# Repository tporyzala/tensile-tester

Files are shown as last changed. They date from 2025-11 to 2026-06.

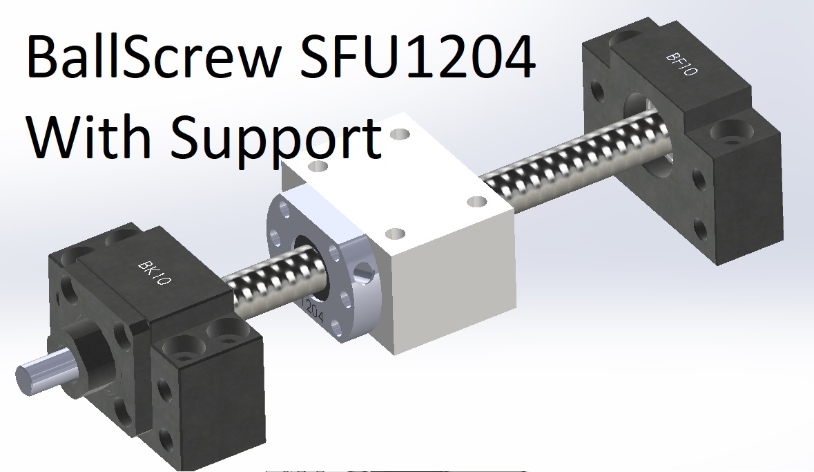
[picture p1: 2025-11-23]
cad/SFU/Sfu1204.jpg

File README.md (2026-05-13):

# Tensile tester repository

This repository contains mechanical, documentation, and experimental assets alongside the software stack.

The software and firmware implementation live under:

```text
src/
```

The source tree currently includes:

- Raspberry Pi FastAPI application
- SQLite persistence layer
- WebSocket/Plotly live telemetry UI
- Arduino Uno firmware for control, safety, telemetry, and button handling
- setup and protocol documentation

See [`src/README.md`](src/README.md) for software architecture, setup, transport selection, serial protocol, and firmware notes.

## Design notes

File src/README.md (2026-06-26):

# Tensile tester ground-zero stack

This `src/` workspace is intentionally small. The current behavior is:

- Arduino Uno reads the HX711 load cell, two jog buttons, and one stop button.
- In setup mode, Button 1 on D2 jogs the load head up while held and Button 2 on D3 jogs it down while held.
- Releasing both jog buttons stops setup jog step pulses. Button 3 on D4 is reported as the stop button.
- During an automated test, Button 1 pauses/resumes and Button 2 or Button 3 stops the run.
- Raspberry Pi serves one automated-test page where the operator defines any number of force or displacement steps.
- The automated-test page keeps an in-memory sample set: one specimen at a time, editable step methods, setup motion sliders, automatic sample numbers, notes, include/exclude controls, force-displacement overlays, setup tare/displacement zeroing, live charts, a raw serial log, and one XLSX workbook export.
- Plots keep accumulating data until the operator clicks the plot Clear button.

There is no database, persistent run storage across app restarts, limit switch handling, overload shutoff, audit trail, ASTM report generation, barcode workflow, or emergency-stop chain in this version.

## Layout

```text
src/
|-- app/
|   |-- __init__.py
|   |-- main.py              FastAPI web API and serial bridge
|   `-- static/
|       |-- test.html        Automated-test page
|       |-- styles.css       Shared page appearance
|       |-- live-charts.js   Plotly chart adapter and navigation
|       |-- vendor/          Vendored browser libraries
|       `-- test.js          Automated-test page behavior
|-- firmware/
|   `-- arduino_uno/
|       |-- include/
|       |   `-- HardwareConfig.h
|       |-- src/
|       |   `-- main.cpp
|       `-- platformio.ini
|-- requirements.txt
|-- tests/
|   `-- test_multisample.py
`-- README.md
```

## How It Works

```text
Arduino:
  HX711 + buttons -> motion/test state machine -> serial telemetry

Python app:
  serial telemetry -> MachineSnapshot/TestRunState -> web API
  web commands -> ACK-confirmed Arduino serial commands
  finalized specimen telemetry -> in-memory sample set

Browser:
  automated page polls /api/test/state
  sends setup motion, test, stop, sample-set, and return-to-zero commands
```

The Arduino owns the hardware loop. It reads the HX711, debounces the buttons, updates the stepper, runs the automated-test state machine, and emits `TEL` telemetry every 100 ms.

The Python app owns serial communication, command acknowledgement, API state, sample-set memory, and XLSX workbook generation. Motion, tare, displacement-zero, and test commands are not treated as successful until the expected Arduino `ACK,...` is consumed.

The browser owns only the operator interface. It does not persist test records. Sample sets live in the Python process and disappear when the app restarts or when the operator clicks Clear Set.

## Current Pinout

The firmware uses `INPUT_PULLUP` for the physical buttons, so each button should connect its Arduino pin to ground when pressed.

```text
Stepper PUL-       D12
Stepper DIR-       D11
Stepper ENA-       D10
HX711 data         D5
HX711 clock        D6
Button 1, up       D2
Button 2, down     D3
Button 3, stop     D4
E-stop             unused in this build
```

The current driver assumption is common-positive signal wiring:

```text
PUL+ -> +5V
DIR+ -> +5V
ENA+ -> +5V
D12  -> PUL-
D11  -> DIR-
D10  -> ENA-
```

The firmware always controls ENA on D10. If your driver enables at the wrong logic level, flip `InvertEnable` in `firmware/arduino_uno/include/HardwareConfig.h`.

## Firmware

Stepper pulses and direction are handled by AccelStepper in `DRIVER` mode. Setup jog uses `setSpeed(...)` plus `runSpeed()` with a small firmware-side speed ramp so acceleration changes take effect while keeping the known-good pulse path.

Important motion, test, load-cell, and timing settings live in:

```text
firmware/arduino_uno/include/HardwareConfig.h
```

Current key values:

```cpp
constexpr uint8_t StepPulse = 12;
constexpr uint8_t StepDirection = 11;
constexpr uint8_t StepEnable = 10;
constexpr uint8_t Hx711Data = 5;
constexpr uint8_t Hx711Clock = 6;
constexpr uint8_t ButtonUp = 2;
constexpr uint8_t ButtonDown = 3;
constexpr uint8_t ButtonStop = 4;

constexpr float MotorStepsPerRev = 200.0f;
constexpr float GearboxRatio = 19.203f;
constexpr float ScrewPitchMmPerRev = 4.0f;
constexpr uint16_t Microstepping = 8;

constexpr float MinJogStepRateStepsS = 50.0f;
constexpr float MaxJogStepRateStepsS = 4000.0f;
constexpr float DefaultJogStepRateStepsS = 4000.0f;
constexpr float MinAccelerationStepsS2 = 100.0f;
constexpr float MaxAccelerationStepsS2 = 10000.0f;
constexpr float DefaultAccelerationStepsS2 = 10000.0f;
constexpr uint32_t StepPulseHighMicros = 20;
constexpr bool InvertDirection = false;
constexpr bool InvertStepPulse = true;
constexpr bool InvertEnable = false;
constexpr bool DisableMotorWhenIdle = false;

constexpr int8_t IncreaseLoadDirection = 1;
constexpr float MinStepRateStepsS = 50.0f;
constexpr float MaxStepRateStepsS = 4000.0f;
constexpr float DefaultMaxStepRateStepsS = 2000.0f;
constexpr float ForceKpStepsPerSecondPerNewton = 12.0f;
constexpr float ForceKiStepsPerSecondPerNewtonSecond = 1.0f;
constexpr float ForceKdStepsPerSecondPerNewtonPerSecond = 0.0f;
constexpr float ForceDeadbandN = 0.20f;
constexpr float ForceIntegralLimitNSeconds = 300.0f;
constexpr uint16_t HeartbeatTimeoutMs = 2000;

constexpr uint8_t Hx711Gain = 128;
constexpr float CalibrationSlopeNPerCount = 0.002283289f;
constexpr float CalibrationInterceptN = 0.0f;
constexpr bool InvertSign = false;
constexpr uint32_t TareDurationMs = 5000;

constexpr uint16_t TelemetryPeriodMs = 100;
constexpr uint16_t ButtonDebounceMs = 25;
```

Setup jog and automated tests intentionally have different speed ceilings:

- Setup jog slider: `50` to `4000 steps/s`, default `4000 steps/s`.
- Automated test max-speed slider: `50` to `4000 steps/s`, default `2000 steps/s`.
- Shared acceleration slider: `100` to `10000 steps/s^2`, default `10000 steps/s^2`.
- With the current mechanics, `2000 steps/s` is about `0.2604 mm/s`, and `10000 steps/s^2` is about `1.3019 mm/s^2`, because the conversion is `200 * 19.203 * 8 / 4 = 7681.2 steps/mm`.

PlatformIO dependencies:

```text
bogde/HX711
waspinator/AccelStepper
```

PlatformIO is the firmware build/upload tool. On a clean Raspberry Pi, install it into the repo virtual environment:

```bash
cd ~/tensile-tester/src
python3 -m venv .venv
source .venv/bin/activate
python -m pip install --upgrade pip
python -m pip install -r requirements.txt
python -m pip install platformio
```

Build firmware on the Pi:

```bash
cd ~/tensile-tester/src/firmware/arduino_uno
platformio run
```

Upload firmware:

```bash
platformio run --target upload --upload-port /dev/ttyACM0
```

If `platformio` is not found, activate the repo virtual environment first:

```bash
cd ~/tensile-tester/src
source .venv/bin/activate
```

If PlatformIO reports a broken JSON file under `.pio/libdeps`, clear the generated local PlatformIO cache and rebuild:

```bash
cd ~/tensile-tester/src/firmware/arduino_uno
rm -rf .pio
platformio run
```

On this Windows checkout, the verified local build command is:

```powershell
cd C:\Users\tomek\Desktop\tensile-tester\src
.\.venv\Scripts\platformio.exe run -d firmware\arduino_uno
```

## Web App

Python dependencies are listed in `requirements.txt`:

```text
fastapi
uvicorn[standard]
pyserial
XlsxWriter
```

Run on the Raspberry Pi:

```bash
cd ~/tensile-tester/src
python3 -m venv .venv
source .venv/bin/activate
python -m pip install --upgrade pip
python -m pip install -r requirements.txt
export TENSILE_SERIAL_PORT=/dev/ttyACM0
python -m uvicorn app.main:app --host 0.0.0.0 --port 8000
```

Open:

```text
http://<raspberry-pi-ip>:8000/test
```

The root URL `http://<raspberry-pi-ip>:8000/` redirects to `/test`.

Optional environment variables:

```text
TENSILE_SERIAL_PORT=/dev/ttyACM0
TENSILE_SERIAL_BAUDRATE=115200
TENSILE_SERIAL_RECONNECT_S=2.0
TENSILE_SERIAL_LOG_MAX_LINES=500
```

On Windows, the default serial port is `COM3`. On Linux/Raspberry Pi, the default is `/dev/ttyACM0`.

## Automated Test Mode

Automated test mode is served at:

```text
http://<raspberry-pi-ip>:8000/test
```

The root URL redirects to `/test`, so there is no separate manual-mode page. The sidebar remains in place with the automated-test entry so more pages can be added later.

The left sidebar switches between Automated Test, Calibration, and Setup. Automated Test keeps the live plots, compact machine status, test actions, method steps, sample set, and raw serial log. Calibration captures averaged raw ADC points, fits a linear load-cell calibration, and reports firmware-ready slope/intercept constants for `HardwareConfig.h`. Setup contains tester motion sliders for physical button jog speed, automated-test maximum step rate, and shared acceleration. Slider changes post to `/api/motion`; the Python app sends `SET_MOTION_LIMITS`, waits for `ACK,SET_MOTION_LIMITS`, and only then reports the applied settings.

An automated test has any number of steps. Each step contains:

- target type and value: force in newtons, or crosshead displacement in millimeters
- rate type and value: force in newtons per second, or crosshead displacement in millimeters per second
- hold duration in seconds; zero means ramp-only

Target and rate types are independent. For example, a step can move at `0.02 mm/s` until it reaches `100 N`, or increase the commanded force at `10 N/s` until it reaches `2.0 mm` displacement. Signed target values allow tension/compression or either crosshead direction; rate values are entered as positive magnitudes.

The step table and motion settings can be saved as named test methods. The save icon opens a name prompt; saving with the same sanitized name overwrites that method, while saving with a new name creates a new method. The load icon opens a scrollable method picker. Loaded methods remain editable before running, and can be saved back to the same method or saved under a new name. Method files are JSON documents stored in `data/test-methods` by default; set `TENSILE_METHOD_DIR` to use another directory.

Methods can optionally run a preload initialization before the specimen sample starts. The preload/unload/zero mode moves at the configured initialization rate until the signed preload force is reached, unloads to the configured unload threshold force (`0 N` by default), holds each point for 1 second, sends `ZERO_DISPLACEMENT`, clears the live plot buffer, then starts the real test steps. Initialization telemetry is a utility run and is not archived as specimen data. The max-travel setting aborts initialization if the preload force is not reached within that displacement window.

Each sample gets an automatic sample number, displayed as `Sample 1`, `Sample 2`, and so on. The notes field is where the operator describes the actual specimen. Notes are limited to 200 characters.

Completed and stopped samples are included by default. Faulted samples are retained in the sample set but excluded from overlays until the operator includes them. The sample table shows index, sample, status, method, point count, peak force, final displacement, include/exclude state, and editable notes. Edited notes are reflected in the XLSX export.

The Tare button posts to `/api/tare`. The Python app sends `ZERO_LOAD`, waits for `ACK,ZERO_LOAD`, then the Arduino treats the average of all fresh load-cell readings collected over 5 seconds as the new zero point. Tare collection is non-blocking, so serial handling, button reads, and stepper updates continue while tare is in progress.

The Zero Displacement button posts to `/api/zero-displacement`. The Python app sends `ZERO_DISPLACEMENT` and waits for `ACK,ZERO_DISPLACEMENT`; the Arduino stores the current step count as the new displayed displacement origin without changing stepper motion tracking.

The automated-test page has fixed `+100`, `+10`, `+1`, `-1`, `-10`, and `-100 mm` relative-move buttons. A button posts its fixed offset to `/api/test/move-relative`; the Python app converts the offset to an absolute displacement target from the latest stationary position and runs one displacement step at the configured automated-test maximum step rate. Relative moves use the same stop and fault handling as Return to Zero and are not archived as specimen samples.

The live charts are rendered with the vendored Plotly basic bundle. The Python app retains every received periodic telemetry point for the live plot buffer until the operator clicks Clear, while the browser incrementally renders only the most recent 5,000 live points. The force-time chart can show or hide the commanded-force trace. The force-displacement chart can overlay finalized included samples; overlay display traces are uniformly reduced to at most 2,000 points per sample and drawn without markers. Chart rendering pauses while the Automated Test tab or browser tab is hidden. The workbook export keeps full retained specimen telemetry.

The Set XLSX link downloads one workbook from `/api/test/samples/csv`. The route name is historical; the response is an `.xlsx` file named `tensile-sample-set.xlsx`. The workbook opens with a Summary worksheet containing one row per sample, included-sample statistics, and peak-force/final-displacement charts for all recorded samples. A Method worksheet shows the saved or latest known editable method snapshot, and a Plots worksheet includes a sampled force-displacement overlay for every sample with telemetry. Chart source data remains visible by default so Excel renders plot lines without hidden-data chart options. Each sample still gets its own raw telemetry worksheet named from the automatic sample number, with Excel-invalid worksheet characters replaced and duplicate names made unique. Telemetry columns and simple numeric metadata are written as spreadsheet numbers, while sample IDs, notes, statuses, and method metadata remain text. The workbook includes the method ID, method name, method hash, and full method snapshot used when that sample started.

The Save Set and Open Set buttons persist and reload the current Sample Set as JSON. Saved sets include finalized sample records, editable notes, include flags, full retained specimen telemetry, the per-sample method snapshots, and the current editable method snapshot. Opening a set replaces the current in-memory Sample Set, reloads that editable method into the step table so more samples can be appended, and is rejected while a test, return-to-zero move, relative move, or faulted run is active. Set files are stored in `data/test-sets` by default; set `TENSILE_SAMPLE_SET_DIR` to use another directory.

The Clear Set button clears all in-memory sample records, active sample metadata, current test steps, and retained test telemetry. It is rejected while a specimen test, return-to-zero move, relative move, or faulted run is active.

Live plots do not clear automatically when a new sample starts or finishes, except after a successful preload initialization so the real test starts visually from the new displacement zero. Use the Live Plots Clear button to clear the plot buffer and reset the chart view. Clearing the plots does not delete retained specimen samples or XLSX export data.

## Return To Zero

Return to Zero is a utility operation, not a specimen sample. Utility telemetry is not archived into the sample set and is not included in the workbook export.

The automated-test page supports two return modes:

- Load: one force-target step to `0 N` at the selected load rate, followed by a 1 second hold. The default rate is `10 N/s`.
- Displacement: one displacement-target step to `0 mm` at the selected displacement rate. The default rate tracks the automated-test maximum step-rate slider.

Return to Zero uses the same `START_TEST` / `TEST_STEP` machinery as specimen tests, but it is tracked as `RETURN_ZERO` in the Python app instead of `SPECIMEN`.

Return to Zero is enabled only when the run state is setup/idle or complete. It is disabled while a specimen test is starting, running, paused, waiting for a step, faulted, or while tare/displacement-zero commands are in flight.

## Stop Behavior

There is no separate abort concept in the current codebase.

Stop means:

- stop motor motion
- finalize any active specimen sample as `STOPPED`
- include that stopped sample in overlays and statistics by default
- return the controller and web run state to setup/idle
- keep the partial sample in the sample set until Clear Set or app restart

In automated test mode, the web Stop button posts to `/api/test/stop`. During a test, physical Button 2 and Button 3 both perform the same stop action. If a run faults, Stop is the operator path back to setup before taring, zeroing displacement, clearing the sample set, or starting a return-to-zero move.

## Lite Operator Protection Model

The firmware separates machine permission from test progress:

```text
Frame mode = what the machine is allowed to do
Test phase = where the current firmware test program is
Fault reason = why the machine stopped abnormally
```

Frame modes:

```text
SETUP    setup jog, tare, and displacement zeroing are allowed
ARMED    a test run exists and the Arduino is waiting for the Pi
TESTING  the Arduino owns automated motion or pause
FAULT    motion is stopped; STOP_TEST returns to SETUP
```

Firmware test phases:

```text
NONE          no firmware test is active
WAITING_STEP  waiting for the Pi to send the next TEST_STEP
RAMPING       following the selected force or displacement rate toward the endpoint
HOLDING       holding the force or displacement endpoint for the requested duration
PAUSED        test is paused by Button 1 or PAUSE_TEST
FAULTED       run stopped due to a fault
```

Python run statuses:

```text
IDLE          no active run
STARTING      Pi is sending START_TEST / first TEST_STEP
RUNNING       active automated step is ramping or holding
PAUSED        run is paused
WAITING_NEXT  Pi is sending the next TEST_STEP
COMPLETE      completed run result remains visible until another run or Clear Set
FAULT         faulted run must be stopped before setup actions are allowed
```

Specimen sample statuses:

```text
COMPLETE  sample completed and is included by default
STOPPED   operator stopped the run; partial sample is retained and included by default
FAULT     run faulted; partial sample is retained but excluded by default
```

Normal specimen flow:

```text
SETUP / NONE
  -> START_TEST
ARMED / WAITING_STEP
  -> TEST_STEP
TESTING / RAMPING
  -> target reached
TESTING / HOLDING
  -> hold time reached
ARMED / WAITING_STEP
  -> next TEST_STEP when steps remain

Final hold complete
  -> EVT,TEST_COMPLETE
  -> Arduino returns to SETUP / NONE
  -> Python finalizes the sample as COMPLETE

STOP_TEST from any active or faulted test
  -> motion stops
  -> any active specimen sample is finalized as STOPPED
  -> Arduino and Python return to SETUP / NONE
```

For a force-rate ramp, the Arduino moves the commanded force at the requested rate and the PID converts force error to motor step rate. For a displacement-rate ramp, the Arduino commands crosshead speed directly until the endpoint is reached. A force endpoint is then held under PID control; a displacement endpoint is held by keeping the motor enabled at the reached position. `Kd` is currently `0.0` because the HX711 force signal can be noisy; start with `Kp` and `Ki` before adding derivative action.

## Web API

Pages:

```text
GET  /      redirects to /test
GET  /test
```

Setup/support API:

```text
POST /api/motion
POST /api/tare
POST /api/zero-displacement
GET  /health
```

Automated-test API:

```text
GET  /api/test/state
GET  /api/test/sample-sets
GET  /api/test/sample-sets/{sample_set_id}
POST /api/test/sample-sets
POST /api/test/sample-sets/{sample_set_id}/open
POST /api/test/start
POST /api/test/return-zero
POST /api/test/move-relative
POST /api/test/pause
POST /api/test/resume
POST /api/test/stop
POST /api/test/samples/clear
POST /api/test/samples/include
POST /api/test/samples/notes
GET  /api/test/samples/overlay
GET  /api/test/plots
POST /api/test/plots/clear
GET  /api/test/samples/csv
```

`POST /api/test/start` accepts the current backward-compatible shape:

```json
{
  "steps": [
    {
      "target_type": "FORCE",
      "target_value": 100.0,
      "rate_type": "FORCE",
      "rate_value_per_s": 10.0,
      "hold_duration_s": 5.0
    }
  ]
}
```

It also accepts optional sample metadata:

```json
{
  "sample": {
    "notes": "first coupon"
  },
  "steps": [
    {
      "target_type": "DISPLACEMENT",
      "target_value": 2.0,
      "rate_type": "DISPLACEMENT",
      "rate_value_per_s": 0.02,
      "hold_duration_s": 0.0
    }
  ]
}
```

## Serial Protocol

The app sends `GET_STATUS` after connecting so the raw serial panel shows both transmit and receive traffic.

Pi to Arduino:

```text
PING
GET_STATUS
SET_MOTION_LIMITS,<jog_speed_steps_s>,<test_max_step_rate_steps_s>,<acceleration_steps_s2>
ZERO_LOAD
ZERO_DISPLACEMENT
START_TEST,<run_id>,<step_count>
TEST_STEP,<run_id>,<step_index>,<target_type>,<target_value>,<rate_type>,<rate_value_per_s>,<hold_duration_ms>
TEST_HB,<run_id>
PAUSE_TEST,<run_id>
RESUME_TEST,<run_id>
STOP_TEST,<run_id>
```

For `TEST_STEP`, both `<target_type>` and `<rate_type>` are `FORCE` or `DISPLACEMENT`. Force PID output and displacement-rate commands are limited by the automated-test maximum step-rate setting before they are applied to the motor.

Acknowledgements:

```text
ACK,PING
ACK,SET_MOTION_LIMITS,<applied_jog_speed_steps_s>,<applied_test_max_step_rate_steps_s>,<applied_acceleration_steps_s2>
ACK,ZERO_LOAD
ACK,ZERO_DISPLACEMENT
ACK,START_TEST,<run_id>
ACK,TEST_STEP,<run_id>,<step_index>
ACK,PAUSE_TEST,<run_id>
ACK,RESUME_TEST,<run_id>
ACK,STOP_TEST,<run_id>
```

Test events:

```text
EVT,STEP_COMPLETE,<run_id>,<step_index>
EVT,TEST_COMPLETE,<run_id>
EVT,TEST_PAUSED,<run_id>
EVT,TEST_RESUMED,<run_id>
EVT,TEST_STOPPED,<run_id>
EVT,TEST_FAULT,<run_id>,HEARTBEAT_TIMEOUT
```

The Pi sends `TEST_HB` every 0.5 seconds during active tests. If the Arduino does not receive a heartbeat for 2 seconds while the test needs one, it stops motion, keeps the motor enabled, enters `FAULT / FAULTED`, and emits `EVT,TEST_FAULT,<run_id>,HEARTBEAT_TIMEOUT`.

Arduino telemetry:

```text
TEL,<seq>,<time_ms>,<frame_mode>,<test_phase>,<fault_reason>,<raw_adc>,<force_n>,<step_rate_steps_s>,<position_mm>,<button_up>,<button_down>,<button_stop>,<jog_speed_steps_s>,<acceleration_steps_s2>,<test_max_step_rate_steps_s>,<test_run_id>,<test_step_index>,<test_step_count>,<test_control_mode>,<test_setpoint_force_n>,<test_setpoint_displacement_mm>,<test_elapsed_ms>
```

Arduino status:

```text
STATUS,<frame_mode>,<test_phase>,<fault_reason>,<raw_adc>,<force_n>,<step_rate_steps_s>,<position_mm>,<button_up>,<button_down>,<button_stop>,<jog_speed_steps_s>,<acceleration_steps_s2>,<test_max_step_rate_steps_s>,<test_run_id>,<test_step_index>,<test_step_count>,<test_control_mode>,<test_setpoint_force_n>,<test_setpoint_displacement_mm>,<test_elapsed_ms>
```

The raw serial log in the web UI prefixes lines with `TX`, `RX`, or `SYS`. To keep long-running browser refreshes responsive, the UI receives only the most recent `TENSILE_SERIAL_LOG_MAX_LINES` lines, defaulting to `500`.

## Local Checks

Useful local verification commands from this checkout:

```powershell
cd C:\Users\tomek\Desktop\tensile-tester\src
.\.venv\Scripts\python.exe -m unittest discover -s tests
.\.venv\Scripts\python.exe -m compileall app tests
node --check app\static\live-charts.js
node --check app\static\test.js
.\.venv\Scripts\platformio.exe run -d firmware\arduino_uno
```

## Current Troubleshooting Notes

If the UI shows button state, step rate, and position changing, the Arduino firmware is commanding steps. Remaining no-motion causes are then outside the button logic:

- driver enable input is disabling the driver
- motor power is missing
- motor coil pairs are incorrect
- current limit is too low
- driver fault/alarm is active
- PUL/DIR polarity does not match the driver wiring

If the motor only moves when it should be disabled, or disables when it should move, flip `InvertEnable` in `HardwareConfig.h`.

If a command works from the UI but the machine state does not change, check the raw serial log for missing or mismatched `ACK,...` lines. The Python app waits for exact ACK tokens and will reject commands that the Arduino does not confirm.

## Safety Scope

This is a bring-up build. It intentionally has no limit switches, software travel limits, overload shutoff, or emergency-stop behavior. Stop is a software/serial stop path, not a safety-rated E-stop. Use low loads and low speeds until independent safety protections are added.

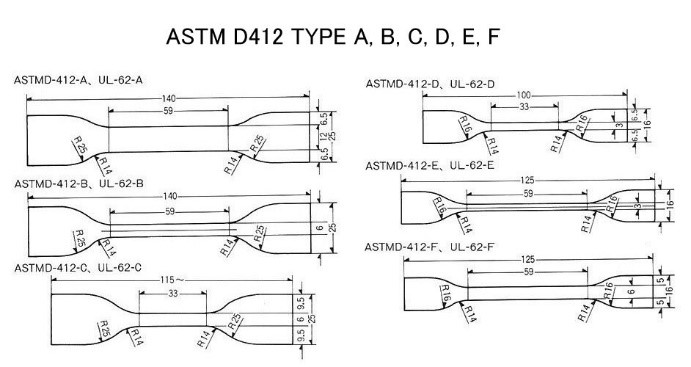
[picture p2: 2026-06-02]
docs/standards/ASTM-D412-specimen-dimension.jpg

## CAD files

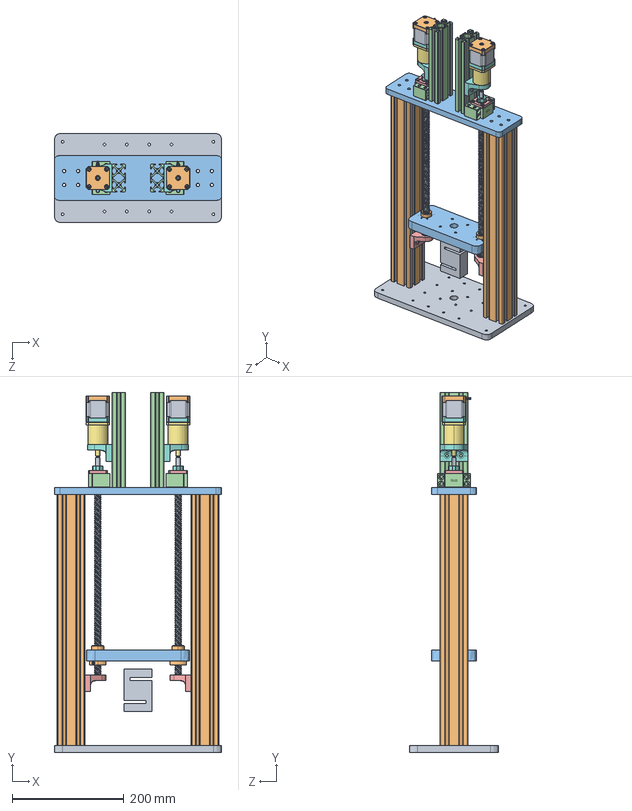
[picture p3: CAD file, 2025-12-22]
cad/Assy.STEP
300.0 x 645.4 x 160.0 mm
Base plate
Column_Default<As Machined> x 2
Top plate
BK10 x 2
SFU Ballscrew_SFU-1204 x 2
SFU Nut_SFU-1204 x 2
Cross head
Top plate column_Default<As Machined> x 2
Ballscrew bearing mount x 2
radial ball bearing_68_am_698-2RS Deep Groove Ball Bearing x 2
NEMA Planetary Gearbox x 2
17HM19-2004S_По умолчанию x 2
Motor bracket x 2
S load cell

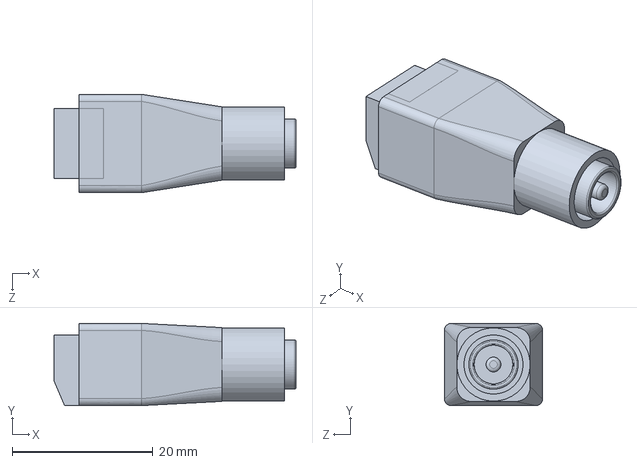
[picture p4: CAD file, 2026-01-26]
cad/Electronics/dc_power_jack_assembly.SLDPRT
34.4 x 11.7 x 14.0 mm

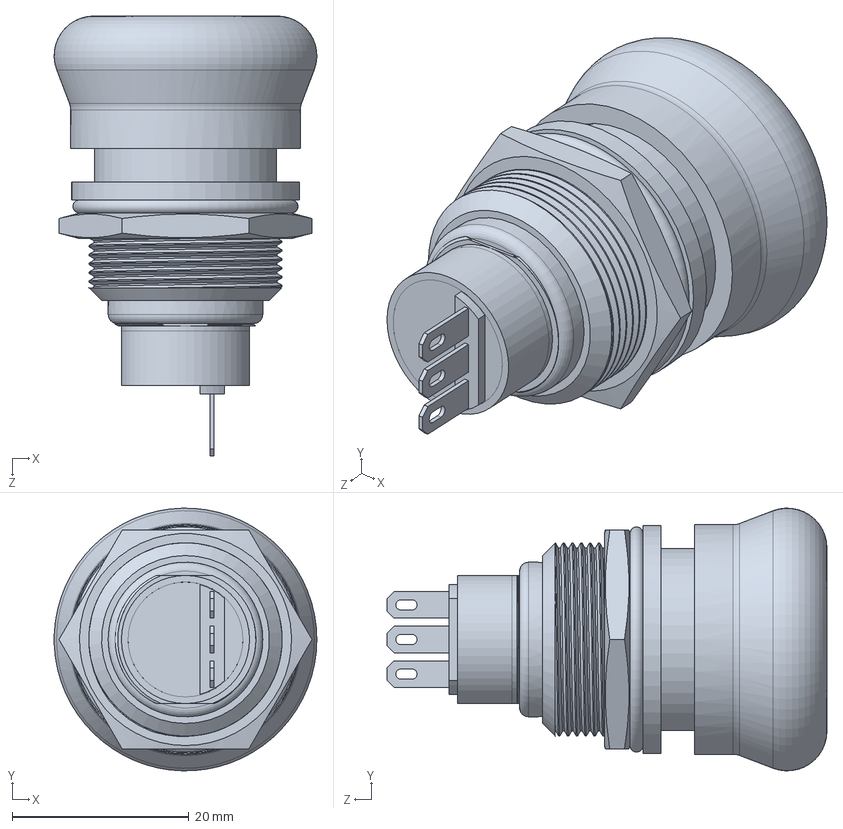
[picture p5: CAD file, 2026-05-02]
cad/Electronics/22mm E-Stop.SLDPRT
29.7 x 29.7 x 49.8 mm

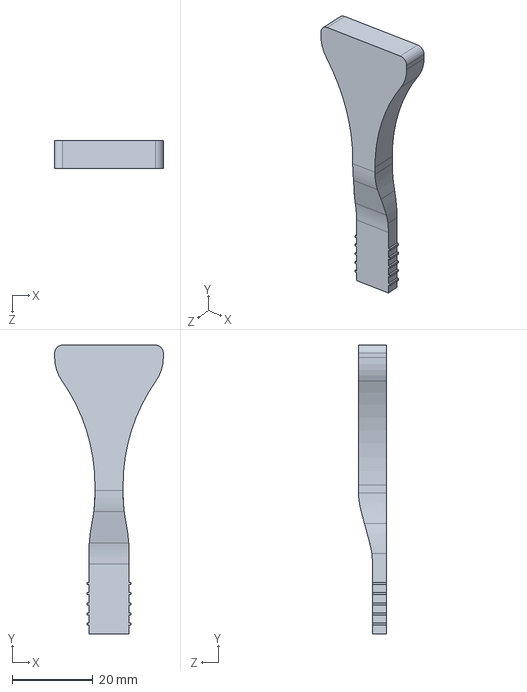
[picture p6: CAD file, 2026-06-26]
cad/Fixtures/Lap Shear Coupon 7x7mm.SLDPRT
27.0 x 71.8 x 7.00 mm

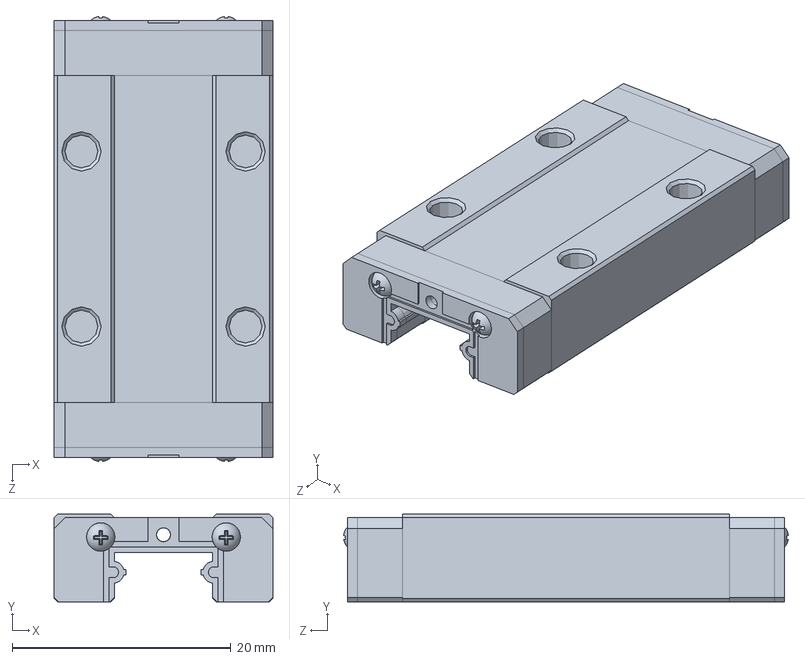
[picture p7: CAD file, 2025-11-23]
cad/MGN9/MGN9-H.SLDPRT
20.0 x 8.00 x 40.7 mm

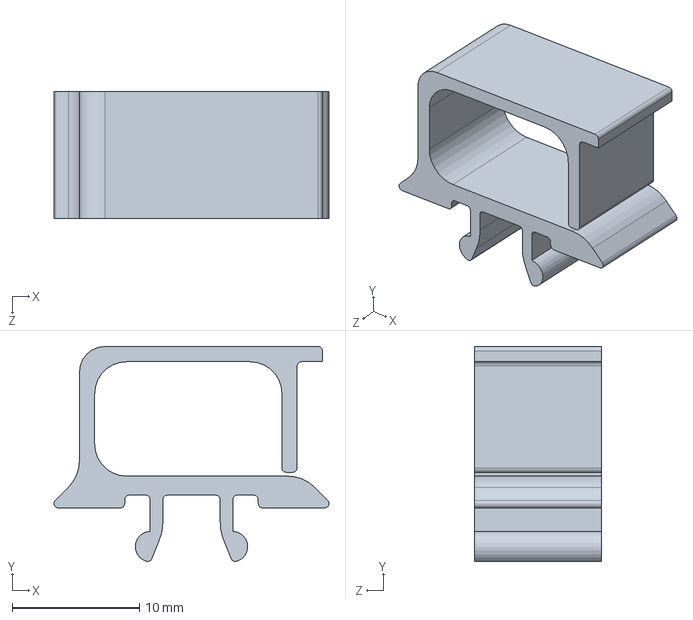
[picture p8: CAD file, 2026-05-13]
cad/Misc/8020 Cable Cap Clip.SLDPRT
21.6 x 16.9 x 10.0 mm

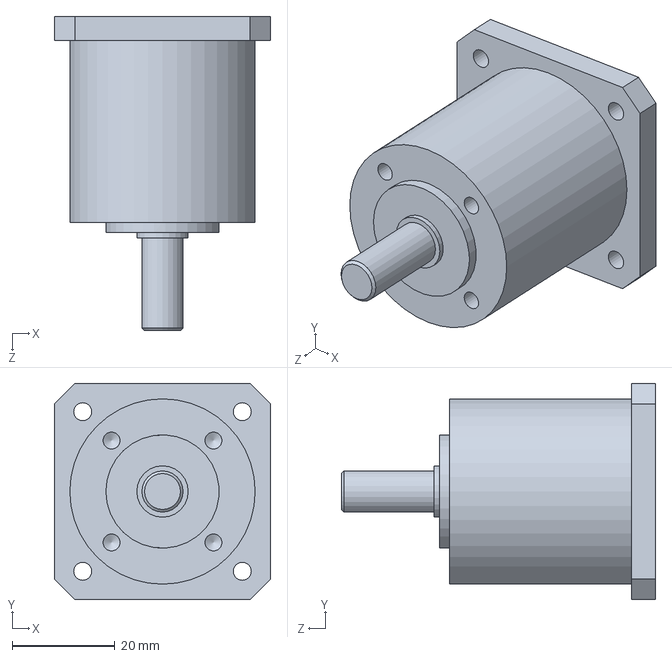
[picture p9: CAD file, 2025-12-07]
cad/NEMA17/NEMA Planetary Gearbox.SLDPRT
42.0 x 42.0 x 61.0 mm

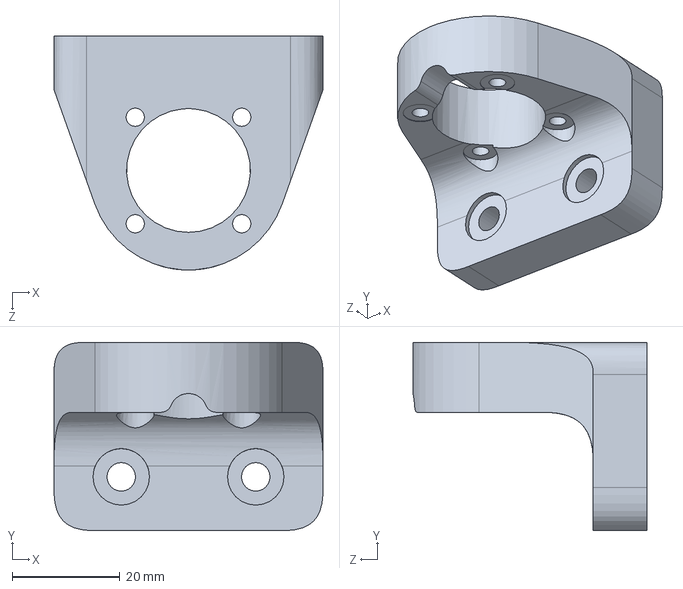
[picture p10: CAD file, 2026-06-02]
cad/Structure/Motor bracket.SLDPRT
50.0 x 35.0 x 43.5 mm

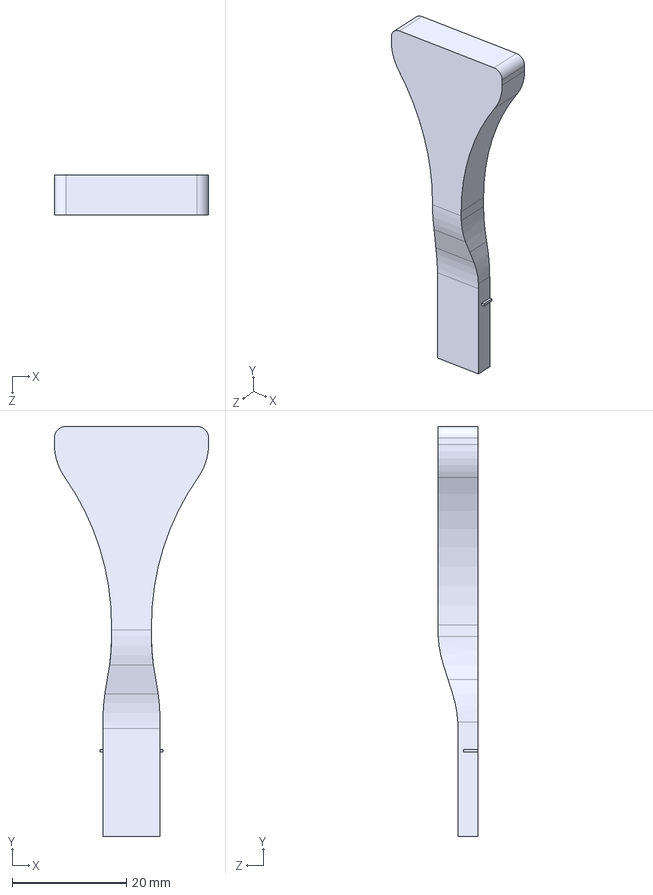
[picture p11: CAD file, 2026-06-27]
cad/toPrint/Lap Shear Coupon 7x7mm.STEP
27.0 x 71.8 x 7.00 mm

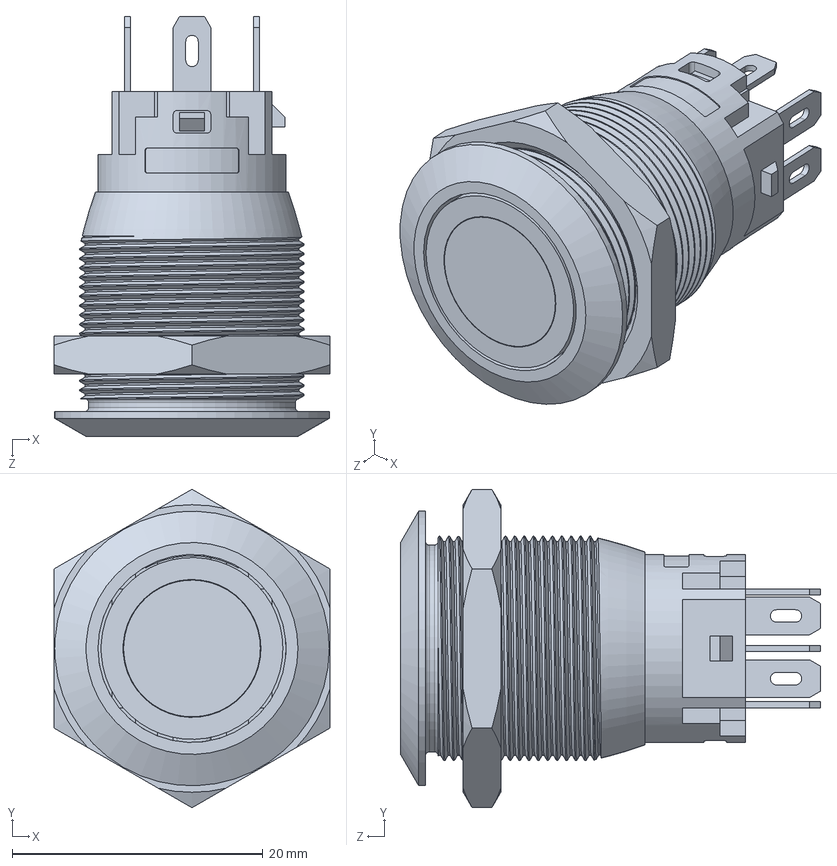
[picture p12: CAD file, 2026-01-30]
cad/Electronics/Push Button M19.SLDPRT
22.0 x 25.4 x 33.5 mm

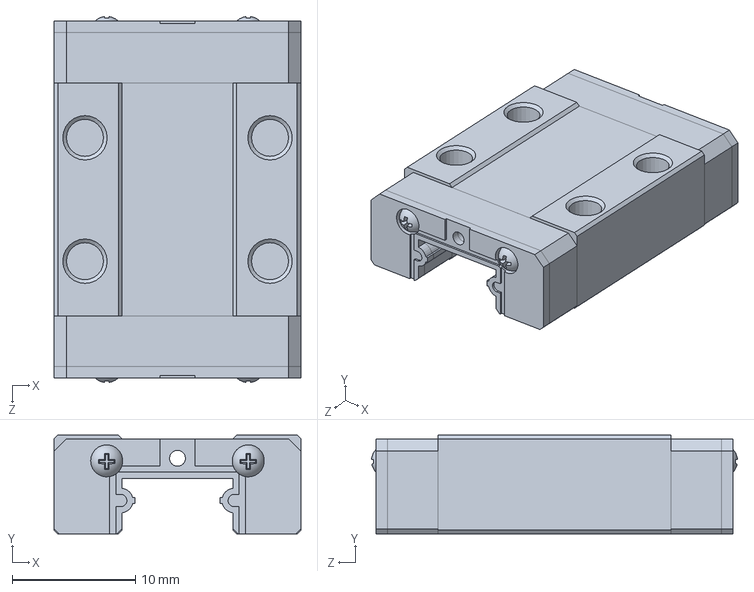
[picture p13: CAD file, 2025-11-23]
cad/MGN9/MGN9-C.SLDPRT
20.0 x 8.00 x 29.7 mm

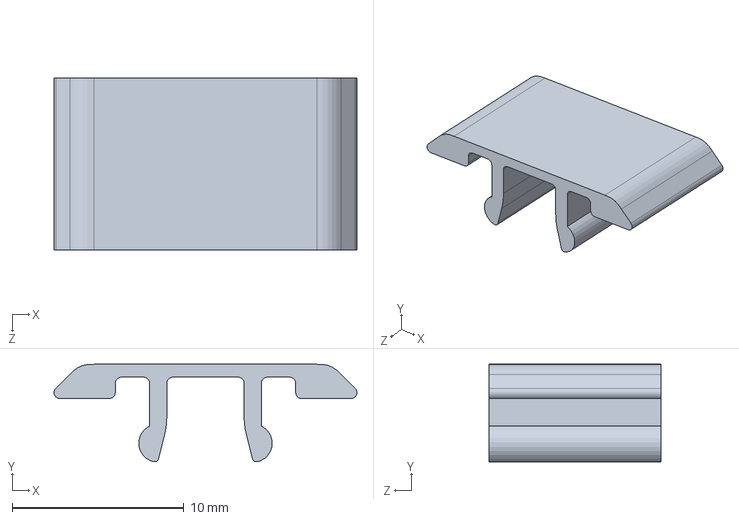
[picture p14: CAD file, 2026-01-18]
cad/Misc/8020 Cable Cap.SLDPRT
17.6 x 5.68 x 10.0 mm

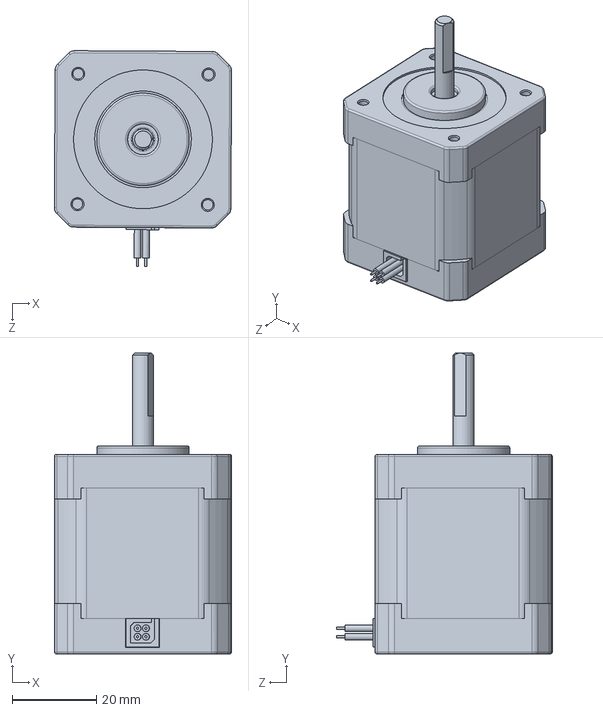
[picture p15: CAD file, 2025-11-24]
cad/NEMA17/17HM19-2004S.SLDPRT
42.2 x 71.6 x 51.3 mm

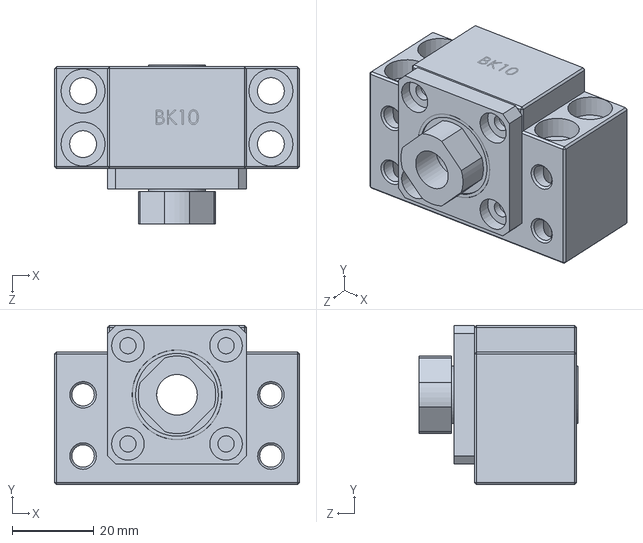
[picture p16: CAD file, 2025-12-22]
cad/SFU/BK10.SLDPRT
60.0 x 39.0 x 39.0 mm

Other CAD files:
cad/Control Box Assy.SLDASM
cad/Fixtures/Tensile Gripper Assy 7x7mm.SLDASM
cad/HX711 Box.SLDASM
cad/Structure/Control Box Face.SLDPRT
cad/Assy.SLDASM
cad/Electronics/GX-16 Connector 6 Pins.SLDPRT
cad/Electronics/HX711.SLDPRT
cad/Electronics/Raspberry Pi 4 Model B.SLDPRT
cad/Electronics/TB6600 - Driver Motor de Passo 4A.stp
cad/Electronics/arduino uno.SLDPRT
cad/Electronics/dc-dc converter.SLDPRT
cad/Electronics/power distribution board.SLDPRT
cad/Fixtures/Tensile Coupon 7x7mm.SLDPRT
cad/Fixtures/Tensile Gripper 7x7mm.SLDPRT
cad/Hardware/#2 5-16in 90065A078_18-8 Stainless Steel Phillips Flat Head Screws for Metal.SLDPRT
cad/Hardware/#5 0p5in 92470A121_Phillips Rounded Head Screws for Sheet Metal.SLDPRT
cad/Hardware/Coupler 8-8mm.SLDPRT
cad/Hardware/M16 Jam Nut 90695A125_Steel Thin Hex Nut.SLDPRT
cad/Hardware/M16 Washer 93475A310_18-8 Stainless Steel Washer.SLDPRT
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

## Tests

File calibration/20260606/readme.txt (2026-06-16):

Did NOT end up applying this callibration since the analytical one was basically spot on and frankly I trust it a bit more than this run.

I was only able to run up to ~2700N before the hacked Eye bolts started yielding and I could not get any more foce into the crane cell.

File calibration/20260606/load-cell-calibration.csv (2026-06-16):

index | reference_force_n | raw_adc_mean | raw_adc_stddev | raw_adc_min | raw_adc_max | sample_count | duration_s | predicted_force_n | residual_force_n
1 | 0 | 3196.275 | 83.68581744636703 | 2915 | 3373 | 120 | 12.008625020000181 | 0 | 0
2 | 4.81 | 6173.941666666667 | 73.21216836853164 | 5950 | 6350 | 120 | 12.01284036800007 | 6.723635011727719 | 1.9136350117277194
3 | 101.81 | 48711.691666666666 | 90.75413634589266 | 48503 | 48961 | 120 | 12.005363960000068 | 102.77478419569304 | 0.9647841956930421
4 | 207.21 | 94907.80833333333 | 73.23891222491558 | 94720 | 95119 | 120 | 12.012966107000011 | 207.08660354838256 | -0.12339645161745239
5 | 514.41 | 227469.80833333332 | 142.1125900963349 | 227121 | 227745 | 120 | 12.005403210000168 | 506.41443443094715 | -7.995565569052815
6 | 1003.81 | 443503.4083333333 | 167.6214234434913 | 443181 | 443873 | 120 | 12.00340673799974 | 994.2229231815062 | -9.587076818493756
7 | 1410.81 | 624314.6638655462 | 233.6941647621545 | 623877 | 624837 | 119 | 12.02748611099969 | 1402.4986048822227 | -8.311395117777238
8 | 1969.81 | 873551.9333333333 | 411.45886253130516 | 872752 | 874477 | 120 | 12.002031581999745 | 1965.2816893625866 | -4.5283106374133695
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

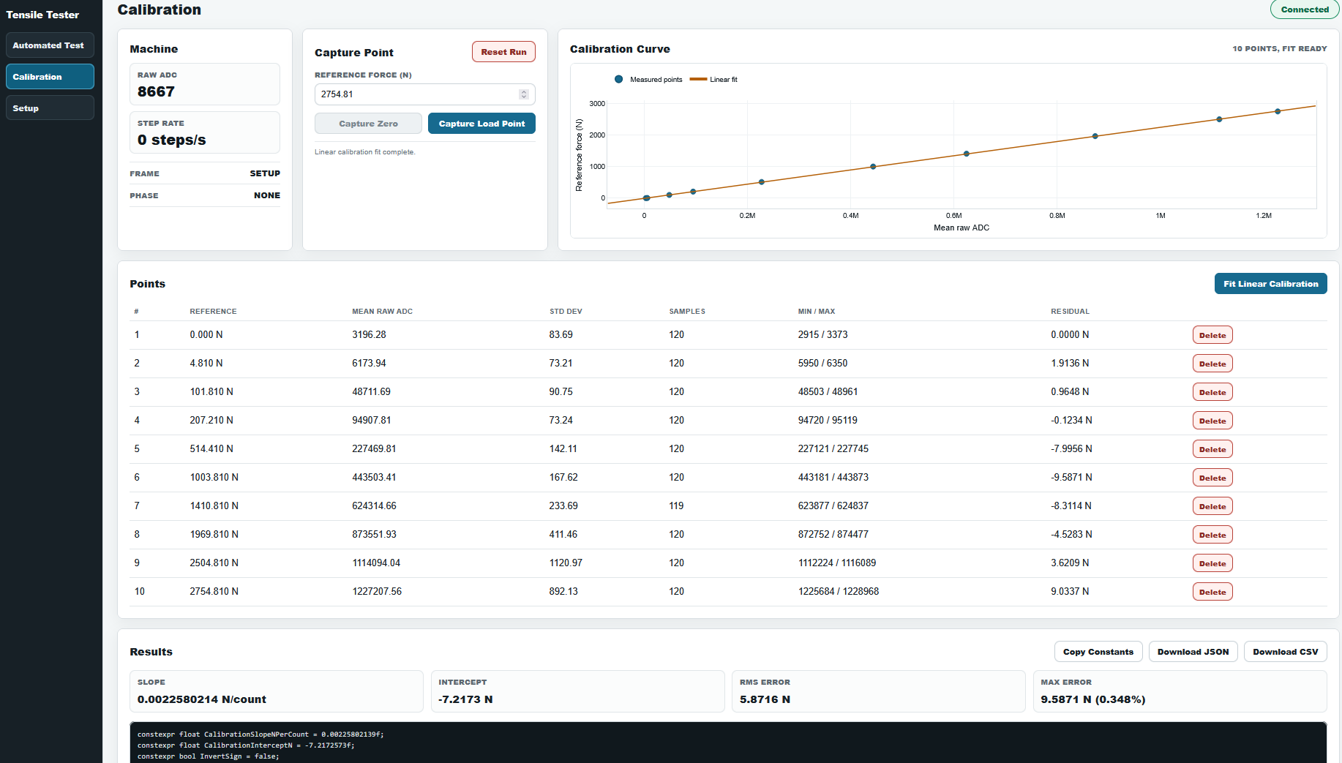
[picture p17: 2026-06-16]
calibration/20260606/2026-06-06 23_09_35-Tensile Tester Test Calibration.png

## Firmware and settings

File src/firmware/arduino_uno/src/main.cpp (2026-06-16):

#include <Arduino.h>
#include <AccelStepper.h>
#include <HX711.h>

#include "HardwareConfig.h"

#include <stdlib.h>
#include <string.h>

/*
  Plain-English firmware map:

  1. setup() runs once when the Arduino powers up or resets.
     It configures the stepper driver, buttons, load-cell board, and serial port.

  2. loop() repeats forever.
     Each pass checks for Pi commands, reads the load cell, reads the jog buttons,
     updates the motor speed, and occasionally sends telemetry back to the Pi.

  3. The Arduino owns the real-time hardware work.
     The Raspberry Pi tells it settings such as jog speed, test speed ceiling,
     and acceleration, but the Arduino decides every loop whether the motor
     should step right now.
*/

namespace {

// Keeps the rest of this file private to this firmware file.
// That matters less for Arduino sketches, but it makes the intent explicit:
// these helpers are internal implementation details, not a reusable library API.

struct DebouncedButton {
  /*
    Mechanical push buttons do not switch cleanly from OFF to ON.
    For a few milliseconds, the electrical signal can chatter between states.

    This small helper turns that noisy raw signal into a stable true/false value:
    - rawDown: what the pin reads right now.
    - stableDown: what we trust after the signal has stayed unchanged long enough.
    - changedAtMs: when the raw signal last changed.
  */
  uint8_t pin = 0;
  bool rawDown = false;
  bool stableDown = false;
  uint32_t changedAtMs = 0;

  void begin(uint8_t assignedPin) {
    // Button wiring uses INPUT_PULLUP:
    // - unpressed button reads HIGH
    // - pressed button connects the pin to ground and reads LOW
    pin = assignedPin;
    pinMode(pin, INPUT_PULLUP);
    rawDown = digitalRead(pin) == LOW;
    stableDown = rawDown;
    changedAtMs = millis();
  }

  void update(uint32_t nowMs) {
    /*
      Pseudo-code:
      - read the pin
      - if the raw value changed, restart the debounce timer
      - if the raw value stayed the same for ButtonDebounceMs, accept it
    */
    const bool down = digitalRead(pin) == LOW;
    if (down != rawDown) {
      rawDown = down;
      changedAtMs = nowMs;
      return;
    }
    if (down != stableDown && (nowMs - changedAtMs) >= HardwareConfig::Timing::ButtonDebounceMs) {
      stableDown = down;
    }
  }
};

// Hardware interfaces. These objects know how to talk to the external boards.
HX711 loadCell;
DebouncedButton upButton;
DebouncedButton downButton;
DebouncedButton stopButton;
AccelStepper stepper(
    AccelStepper::DRIVER,
    HardwareConfig::Pins::StepPulse,
    HardwareConfig::Pins::StepDirection);

/*
  Load-cell zeroing:
  - rawAdc is the raw HX711 number.
  - rawForceN() converts rawAdc into force using the calibration constants.
  - tareRawAdc stores the raw reading that should be treated as zero.
  - operator tare commands average fresh HX711 readings for a timed window.
  - measuredForceN() reports force relative to tareRawAdc.
*/
long rawAdc = 0;
bool tareSet = false;
float tareRawAdc = 0.0f;
bool tareAveraging = false;
float tareRawAdcSum = 0.0f;
uint32_t tareSamplesCollected = 0;
uint32_t tareStartedAtMs = 0;

/*
  Jog motion state:
  - jogDirection is -1, 0, or +1 based on the two physical buttons.
  - targetStepRateStepsS is the speed we want.
  - commandedStepRateStepsS is the speed currently being sent to AccelStepper.
  - commandedStepRateStepsS ramps toward targetStepRateStepsS using accelerationStepsS2.

  That ramp is what prevents the motor command from jumping instantly from
  stopped to full speed.
*/
bool motorEnabled = false;
int8_t jogDirection = 0;
float jogSpeedStepsS = HardwareConfig::Motion::DefaultJogStepRateStepsS;
float testMaxStepRateStepsS = HardwareConfig::Test::DefaultMaxStepRateStepsS;
float accelerationStepsS2 = HardwareConfig::Motion::DefaultAccelerationStepsS2;
float targetStepRateStepsS = 0.0f;
float commandedStepRateStepsS = 0.0f;
uint32_t lastMotionUpdateMicros = 0;
long displacementZeroSteps = 0;

uint32_t telemetrySeq = 0;
uint32_t lastTelemetryMs = 0;

/*
  Lite operator-protection model:

  SETUP   -> setup jog, tare, and displacement zeroing are allowed.
  ARMED   -> a test run exists, but the Arduino is waiting for the Pi.
  TESTING -> the Arduino owns automated motion or pause.
  FAULT   -> motion is stopped; STOP_TEST returns to setup.

  Test phases are separate from frame modes. That keeps "what the machine may do"
  separate from "where the test program is".
*/
enum FrameMode : uint8_t {
  FRAME_SETUP,
  FRAME_ARMED,
  FRAME_TESTING,
  FRAME_FAULT
};

enum TestPhase : uint8_t {
  TEST_NONE,
  TEST_WAITING_STEP,
  TEST_RAMPING,
  TEST_HOLDING,
  TEST_PAUSED,
  TEST_FAULTED
};

enum TestValueType : uint8_t {
  TEST_VALUE_FORCE,
  TEST_VALUE_DISPLACEMENT
};

enum TestControlMode : uint8_t {
  TEST_CONTROL_NONE,
  TEST_CONTROL_FORCE,
  TEST_CONTROL_DISPLACEMENT
};

enum FaultReason : uint8_t {
  FAULT_NONE,
  FAULT_HEARTBEAT_TIMEOUT
};

// One record describes the active automated-test program and its current step.
struct ActiveTestStep {
  TestValueType targetType = TEST_VALUE_FORCE;
  float targetValue = 0.0f;
  TestValueType rateType = TEST_VALUE_FORCE;
  float rateValuePerS = 0.0f;
  uint32_t holdDurationMs = 0;
};

struct TestControllerState {
  FrameMode frameMode = FRAME_SETUP;
  TestPhase phase = TEST_NONE;
  TestPhase resumePhase = TEST_NONE;
  FaultReason faultReason = FAULT_NONE;
  uint16_t runId = 0;
  uint16_t stepIndex = 0;
  uint16_t stepCount = 0;
  ActiveTestStep step;
  TestControlMode controlMode = TEST_CONTROL_NONE;
  float stepStartForceN = 0.0f;
  float stepStartDisplacementMm = 0.0f;
  float setpointForceN = 0.0f;
  float setpointDisplacementMm = 0.0f;
  uint32_t stepStartedAtMs = 0;
  uint32_t holdStartedAtMs = 0;
  uint32_t pauseStartedAtMs = 0;
  uint32_t lastHeartbeatMs = 0;
};

/*
  Instron-lite state model:
  - frameMode says what the machine is allowed to do.
  - testPhase says where the current test program is.
  - faultReason says why the machine stopped abnormally.
  - The Pi stores the full step list.
  - The Arduino stores only the active step and keeps running it in real time.
  - One step has an end condition and an independent rate-control type.
  - A force endpoint is held with PID; a displacement endpoint is held in position.
*/
TestControllerState test;
bool lastPauseButtonDown = false;
bool lastStopButtonDown = false;
bool lastButton3StopDown = false;
float forcePidIntegralNSeconds = 0.0f;
float forcePidLastErrorN = 0.0f;
uint32_t forcePidLastUpdateMs = 0;
bool forcePidHasLastError = false;

// Serial commands arrive as bytes. This buffer collects them until a newline.
char serialBuffer[96] = {0};
uint8_t serialBufferIndex = 0;

float absoluteFloat(float value) {
  // Same idea as abs(), but explicit for float values.
  return value >= 0.0f ? value : -value;
}

float clampFloat(float value, float minValue, float maxValue) {
  // Keep a setting inside a safe range before applying it to hardware.
  if (value < minValue) {
    return minValue;
  }
  if (value > maxValue) {
    return maxValue;
  }
  return value;
}

float signFloat(float value) {
  if (value > 0.0f) {
    return 1.0f;
  }
  if (value < 0.0f) {
    return -1.0f;
  }
  return 0.0f;
}

float stepsPerMm() {
  /*
    Convert motor steps into crosshead travel.

    For one screw revolution:
    - the motor must turn through the gearbox
    - each motor revolution has MotorStepsPerRev full steps
    - microstepping multiplies the number of step pulses
    - the screw pitch converts screw rotation into millimeters
  */
  return (
      HardwareConfig::Motion::MotorStepsPerRev *
      HardwareConfig::Motion::GearboxRatio *
      static_cast<float>(HardwareConfig::Motion::Microstepping)) /
      HardwareConfig::Motion::ScrewPitchMmPerRev;
}

float positionMm() {
  // Keep motor tracking intact while reporting travel relative to the operator-selected zero.
  return (
      static_cast<float>(stepper.currentPosition()) -
      static_cast<float>(displacementZeroSteps)) /
      stepsPerMm();
}

float forceFromRawAdc(float adc) {
  /*
    Convert HX711 counts to force.

    This is a simple straight-line calibration:
      force = slope * rawAdc + intercept

    If the load cell sign is backwards for your wiring/mechanics, InvertSign
    flips tension/compression direction without changing the calibration numbers.
  */
  float force = (
      HardwareConfig::LoadCell::CalibrationSlopeNPerCount * adc) +
      HardwareConfig::LoadCell::CalibrationInterceptN;
  if (HardwareConfig::LoadCell::InvertSign) {
    force = -force;
  }
  return force;
}

float rawForceN() {
  return forceFromRawAdc(static_cast<float>(rawAdc));
}

float measuredForceN() {
  // Report force relative to the current tare/zero point.
  const float force = rawForceN();
  return tareSet ? (force - forceFromRawAdc(tareRawAdc)) : force;
}

void beginTareAverage(uint32_t nowMs) {
  /*
    Start a non-blocking tare.

    The loop keeps servicing serial, buttons, and step pulses while the HX711
    produces fresh readings. Each ready reading contributes one sample for the
    full tare time window, and ACK is sent only after the averaged zero is applied.
  */
  tareAveraging = true;
  tareRawAdcSum = 0.0f;
  tareSamplesCollected = 0;
  tareStartedAtMs = nowMs;
}

void completeTareAverage() {
  if (tareSamplesCollected == 0) {
    tareAveraging = false;
    Serial.println(F("ERR,TARE_NO_SAMPLES"));
    return;
  }

  tareRawAdc = tareRawAdcSum / static_cast<float>(tareSamplesCollected);
  tareSet = true;
  tareAveraging = false;
  Serial.println(F("ACK,ZERO_LOAD"));
}

void addTareSample() {
  tareRawAdcSum += static_cast<float>(rawAdc);
  ++tareSamplesCollected;
}

const char* testPhaseName() {
  switch (test.phase) {
    case TEST_WAITING_STEP:
      return "WAITING_STEP";
    case TEST_RAMPING:
      return "RAMPING";
    case TEST_HOLDING:
      return "HOLDING";
    case TEST_PAUSED:
      return "PAUSED";
    case TEST_FAULTED:
      return "FAULTED";
    case TEST_NONE:
    default:
      return "NONE";
  }
}

const char* frameModeName() {
  switch (test.frameMode) {
    case FRAME_ARMED:
      return "ARMED";
    case FRAME_TESTING:
      return "TESTING";
    case FRAME_FAULT:
      return "FAULT";
    case FRAME_SETUP:
    default:
      return "SETUP";
  }
}

const char* faultReasonName() {
  switch (test.faultReason) {
    case FAULT_HEARTBEAT_TIMEOUT:
      return "HEARTBEAT_TIMEOUT";
    case FAULT_NONE:
    default:
      return "NONE";
  }
}

const char* testControlModeName() {
  switch (test.controlMode) {
    case TEST_CONTROL_FORCE:
      return "FORCE";
    case TEST_CONTROL_DISPLACEMENT:
      return "DISPLACEMENT";
    case TEST_CONTROL_NONE:
    default:
      return "NONE";
  }
}

bool parseTestValueType(const char* token, TestValueType& value) {
  if (strcmp(token, "FORCE") == 0) {
    value = TEST_VALUE_FORCE;
    return true;
  }
  if (strcmp(token, "DISPLACEMENT") == 0) {
    value = TEST_VALUE_DISPLACEMENT;
    return true;
  }
  return false;
}

void setMotorEnabled(bool enabled) {
  /*
    The enable pin is part of this machine's wiring.
    This helper keeps our software state and the driver output state together.
  */
  if (motorEnabled == enabled) {
    return;
  }
  motorEnabled = enabled;
  if (enabled) {
    stepper.enableOutputs();
  } else {
    stepper.disableOutputs();
  }
}

void resetForcePid() {
  forcePidIntegralNSeconds = 0.0f;
  forcePidLastErrorN = 0.0f;
  forcePidLastUpdateMs = 0;
  forcePidHasLastError = false;
}

bool testModeActive() {
  return test.phase != TEST_NONE;
}

bool testNeedsHeartbeat() {
  return (
      test.phase == TEST_WAITING_STEP ||
      test.phase == TEST_RAMPING ||
      test.phase == TEST_HOLDING ||
      test.phase == TEST_PAUSED ||
      test.frameMode == FRAME_TESTING);
}

void stopMotionNow() {
  jogDirection = 0;
  targetStepRateStepsS = 0.0f;
  commandedStepRateStepsS = 0.0f;
  stepper.setSpeed(0.0f);
  resetForcePid();
}

float updateForcePid(float commandedForceN, float measuredForceN, uint32_t nowMs) {
  /*
    The test state machine decides the commanded force.
    This PID turns force error into motor speed for both ramp and hold.

    D is wired in but intentionally configured to zero for now. HX711 readings
    can be noisy, and derivative gain can make the actuator twitch until the
    rest of the machine is characterized.
  */
  const float errorN = commandedForceN - measuredForceN;
  if (absoluteFloat(errorN) <= HardwareConfig::Test::ForceDeadbandN) {
    forcePidIntegralNSeconds = 0.0f;
    forcePidLastErrorN = errorN;
    forcePidLastUpdateMs = nowMs;
    forcePidHasLastError = true;
    return 0.0f;
  }

  float dtS = 0.0f;
  if (forcePidLastUpdateMs != 0) {
    dtS = static_cast<float>(nowMs - forcePidLastUpdateMs) / 1000.0f;
  }

  if (
      forcePidHasLastError &&
      signFloat(errorN) != 0.0f &&
      signFloat(forcePidLastErrorN) != 0.0f &&
      signFloat(errorN) != signFloat(forcePidLastErrorN)) {
    forcePidIntegralNSeconds = 0.0f;
  }

  if (dtS > 0.0f) {
    forcePidIntegralNSeconds += errorN * dtS;
    forcePidIntegralNSeconds = clampFloat(
        forcePidIntegralNSeconds,
        -HardwareConfig::Test::ForceIntegralLimitNSeconds,
        HardwareConfig::Test::ForceIntegralLimitNSeconds);
  }

  const float derivativeNPerS =
      (forcePidHasLastError && dtS > 0.0f)
          ? ((errorN - forcePidLastErrorN) / dtS)
          : 0.0f;
  forcePidLastErrorN = errorN;
  forcePidLastUpdateMs = nowMs;
  forcePidHasLastError = true;

  const float pidStepRate =
      (HardwareConfig::Test::ForceKpStepsPerSecondPerNewton * errorN) +
      (HardwareConfig::Test::ForceKiStepsPerSecondPerNewtonSecond * forcePidIntegralNSeconds) +
      (HardwareConfig::Test::ForceKdStepsPerSecondPerNewtonPerSecond * derivativeNPerS);

  const float requestedStepRate =
      pidStepRate * static_cast<float>(HardwareConfig::Test::IncreaseLoadDirection);
  return clampFloat(
      requestedStepRate,
      -testMaxStepRateStepsS,
      testMaxStepRateStepsS);
}

bool targetReached(float startValue, float currentValue, float targetValue) {
  const float direction = signFloat(targetValue - startValue);
  if (direction == 0.0f) {
    return true;
  }
  return direction > 0.0f
      ? currentValue >= targetValue
      : currentValue <= targetValue;
}

float forceRampDirection() {
  if (test.step.targetType == TEST_VALUE_FORCE) {
    return signFloat(test.step.targetValue - test.stepStartForceN);
  }
  return (
      signFloat(test.step.targetValue - test.stepStartDisplacementMm) *
      static_cast<float>(HardwareConfig::Test::IncreaseLoadDirection));
}

float displacementRampDirection() {
  if (test.step.targetType == TEST_VALUE_DISPLACEMENT) {
    return signFloat(test.step.targetValue - test.stepStartDisplacementMm);
  }
  return (
      signFloat(test.step.targetValue - test.stepStartForceN) *
      static_cast<float>(HardwareConfig::Test::IncreaseLoadDirection));
}

void enterTestHold(uint32_t nowMs) {
  test.holdStartedAtMs = nowMs;
  if (test.step.targetType == TEST_VALUE_FORCE) {
    test.controlMode = TEST_CONTROL_FORCE;
    test.setpointForceN = test.step.targetValue;
    resetForcePid();
  } else {
    test.controlMode = TEST_CONTROL_DISPLACEMENT;
    test.setpointDisplacementMm = test.step.targetValue;
    stopMotionNow();
  }
  test.frameMode = FRAME_TESTING;
  test.phase = TEST_HOLDING;
}

void emitTestEvent(const __FlashStringHelper* eventName) {
  Serial.print(F("EVT,"));
  Serial.print(eventName);
  Serial.print(',');
  Serial.println(test.runId);
}

void emitTestEventWithStep(const __FlashStringHelper* eventName) {
  Serial.print(F("EVT,"));
  Serial.print(eventName);
  Serial.print(',');
  Serial.print(test.runId);
  Serial.print(',');
  Serial.println(test.stepIndex);
}

void armTestProgram(uint16_t runId, uint16_t stepCount, uint32_t nowMs) {
  stopMotionNow();
  setMotorEnabled(true);
  test = TestControllerState{};
  test.runId = runId;
  test.stepCount = stepCount;
  test.setpointForceN = measuredForceN();
  test.setpointDisplacementMm = positionMm();
  test.step.targetValue = test.setpointForceN;
  test.lastHeartbeatMs = nowMs;
  test.frameMode = FRAME_ARMED;
  test.phase = TEST_WAITING_STEP;
}

bool startTestStep(
    uint16_t runId,
    uint16_t stepIndex,
    TestValueType targetType,
    float targetValue,
    TestValueType rateType,
    float rateValuePerS,
    uint32_t holdDurationMs,
    uint32_t nowMs) {
  if (runId != test.runId || test.frameMode != FRAME_ARMED || test.phase != TEST_WAITING_STEP) {
    return false;
  }
  if (stepIndex == 0 || stepIndex > test.stepCount || rateValuePerS <= 0.0f) {
    return false;
  }

  stopMotionNow();
  setMotorEnabled(true);
  test.stepIndex = stepIndex;
  test.step.targetType = targetType;
  test.step.targetValue = targetValue;
  test.step.rateType = rateType;
  test.step.rateValuePerS = rateValuePerS;
  test.step.holdDurationMs = holdDurationMs;
  test.controlMode = rateType == TEST_VALUE_FORCE
      ? TEST_CONTROL_FORCE
      : TEST_CONTROL_DISPLACEMENT;
  test.stepStartForceN = measuredForceN();
  test.stepStartDisplacementMm = positionMm();
  test.setpointForceN = test.stepStartForceN;
  test.setpointDisplacementMm = test.stepStartDisplacementMm;
  test.stepStartedAtMs = nowMs;
  test.holdStartedAtMs = 0;
  test.lastHeartbeatMs = nowMs;
  test.frameMode = FRAME_TESTING;
  test.phase = TEST_RAMPING;
  return true;
}

void pauseActiveTest(uint32_t nowMs) {
  if (test.phase != TEST_RAMPING && test.phase != TEST_HOLDING) {
    return;
  }
  test.resumePhase = test.phase;
  test.pauseStartedAtMs = nowMs;
  test.frameMode = FRAME_TESTING;
  test.phase = TEST_PAUSED;
  stopMotionNow();
  setMotorEnabled(true);
  emitTestEvent(F("TEST_PAUSED"));
}

void resumeActiveTest(uint32_t nowMs) {
  if (test.phase != TEST_PAUSED) {
    return;
  }
  const uint32_t pausedMs = nowMs - test.pauseStartedAtMs;
  test.stepStartedAtMs += pausedMs;
  if (test.resumePhase == TEST_HOLDING && test.holdStartedAtMs > 0) {
    test.holdStartedAtMs += pausedMs;
  }
  test.lastHeartbeatMs = nowMs;
  test.frameMode = FRAME_TESTING;
  test.phase = test.resumePhase;
  test.resumePhase = TEST_NONE;
  emitTestEvent(F("TEST_RESUMED"));
}

void stopActiveTest() {
  if (!testModeActive()) {
    return;
  }
  const uint16_t stoppedRunId = test.runId;
  stopMotionNow();
  test = TestControllerState{};
  setMotorEnabled(!HardwareConfig::Motion::DisableMotorWhenIdle);
  Serial.print(F("EVT,TEST_STOPPED,"));
  Serial.println(stoppedRunId);
}

void returnToSetupAfterSuccessfulTest() {
  test = TestControllerState{};
  setMotorEnabled(!HardwareConfig::Motion::DisableMotorWhenIdle);
}

void faultActiveTest(FaultReason reason) {
  if (!testModeActive()) {
    return;
  }
  stopMotionNow();
  test.controlMode = TEST_CONTROL_NONE;
  setMotorEnabled(true);
  test.faultReason = reason;
  test.frameMode = FRAME_FAULT;
  test.phase = TEST_FAULTED;
  Serial.print(F("EVT,TEST_FAULT,"));
  Serial.print(test.runId);
  Serial.print(',');
  Serial.println(faultReasonName());
}

bool handleTestButtons(uint32_t nowMs) {
  const bool pausePressed = upButton.stableDown && !lastPauseButtonDown;
  const bool button2StopPressed = downButton.stableDown && !lastStopButtonDown;
  const bool button3StopPressed = stopButton.stableDown && !lastButton3StopDown;
  const bool stopPressed = button2StopPressed || button3StopPressed;
  lastPauseButtonDown = upButton.stableDown;
  lastStopButtonDown = downButton.stableDown;
  lastButton3StopDown = stopButton.stableDown;

  if (!testModeActive()) {
    return false;
  }

  if (stopPressed) {
    stopActiveTest();
  } else if (test.frameMode != FRAME_FAULT && pausePressed) {
    if (test.phase == TEST_PAUSED) {
      resumeActiveTest(nowMs);
    } else {
      pauseActiveTest(nowMs);
    }
  }

  if (test.phase == TEST_NONE) {
    return true;
  }
  setMotorEnabled(true);
  return true;
}
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
void loop() {
  uint32_t nowMs = millis();

  /*
    Main control loop, repeated as fast as possible:

    1. processSerial()
       Check whether the Pi sent a command.

    2. updateLoadCell()
       Read force if the HX711 has a fresh value and advance any tare average.

    3. updateButtons()
       Convert physical button state into jog or test-control commands.

    4. updateTestController()
       During a test, apply the selected force or displacement rate control.

    5. updateStepper()
       Ramp toward the target speed and generate step pulses.

    6. emitTelemetry()
       Every TelemetryPeriodMs, report the current machine state to the Pi.
  */
  processSerial();
  // Commands handled above may use millis() internally. Refresh nowMs so the
  // test heartbeat check cannot compare an older loop timestamp to a newer
  // command timestamp and look like it timed out.
  nowMs = millis();
  updateLoadCell(nowMs);
  updateButtons(nowMs);
  updateTestController(nowMs);
  updateStepper();

  if ((nowMs - lastTelemetryMs) >= HardwareConfig::Timing::TelemetryPeriodMs) {
    emitTelemetry(nowMs);
    lastTelemetryMs = nowMs;
  }
}

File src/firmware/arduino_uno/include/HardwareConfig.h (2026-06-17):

#pragma once

#include <Arduino.h>

namespace HardwareConfig {
namespace Pins {
// Arduino pins wired to the stepper driver, HX711 load cell board, and jog buttons.
constexpr uint8_t StepPulse = 12;
constexpr uint8_t StepDirection = 11;
constexpr uint8_t StepEnable = 10;
constexpr uint8_t Hx711Data = 5;
constexpr uint8_t Hx711Clock = 6;
constexpr uint8_t ButtonUp = 2;
constexpr uint8_t ButtonDown = 3;
constexpr uint8_t ButtonStop = 4;
}

namespace Motion {
// Mechanical conversion from motor rotation to crosshead travel.
constexpr float MotorStepsPerRev = 200.0f;
constexpr float GearboxRatio = 19.203f;
constexpr float ScrewPitchMmPerRev = 4.0f;
constexpr uint16_t Microstepping = 8;

// Jog limits are expressed in motor steps per second and steps per second squared.
constexpr float MinJogStepRateStepsS = 50.0f;
constexpr float MaxJogStepRateStepsS = 4000.0f;
constexpr float DefaultJogStepRateStepsS = 4000.0f;
constexpr float MinAccelerationStepsS2 = 100.0f;
constexpr float MaxAccelerationStepsS2 = 10000.0f;
constexpr float DefaultAccelerationStepsS2 = 10000.0f;
constexpr uint32_t StepPulseHighMicros = 20;

// Driver polarity and enable behavior depend on the exact stepper driver wiring.
constexpr bool InvertDirection = false;
constexpr bool InvertStepPulse = true;
constexpr bool InvertEnable = false;
constexpr bool DisableMotorWhenIdle = false; // keep false to hold position when not jogging
}

namespace Test {
// Positive force error means the controller needs to increase the measured load.
// Flip this to -1 if the test moves away from the requested load on hardware.
constexpr int8_t IncreaseLoadDirection = 1;
constexpr float MinStepRateStepsS = 50.0f;
constexpr float MaxStepRateStepsS = 4000.0f;
constexpr float DefaultMaxStepRateStepsS = 2000.0f;
constexpr float ForceKpStepsPerSecondPerNewton = 12.0f;
constexpr float ForceKiStepsPerSecondPerNewtonSecond = 1.0f;
constexpr float ForceKdStepsPerSecondPerNewtonPerSecond = 0.0f;
constexpr float ForceDeadbandN = 0.20f;
constexpr float ForceIntegralLimitNSeconds = 300.0f;
constexpr uint16_t HeartbeatTimeoutMs = 2000;
}

namespace LoadCell {
// HX711 channel A gain. The bogde/HX711 library defaults to 128, but keep it explicit.
constexpr uint8_t Hx711Gain = 128;
// Force calibration maps raw HX711 counts to newtons: force = slope * counts + intercept.
constexpr float CalibrationSlopeNPerCount = 0.002283289f;
constexpr float CalibrationInterceptN = 0.0f;
constexpr bool InvertSign = false;
// An operator tare averages every fresh HX711 reading collected in this time window.
constexpr uint32_t TareDurationMs = 5000;
}

namespace Timing {
// Telemetry is sent every 100 ms; button input must be stable for 25 ms.
constexpr uint16_t TelemetryPeriodMs = 100;
constexpr uint16_t ButtonDebounceMs = 25;
}
}

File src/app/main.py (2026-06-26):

from __future__ import annotations

import asyncio
import hashlib
import json
import math
import os
import platform
import re
import time
from collections import deque
from collections.abc import AsyncIterator, Awaitable, Callable
from contextlib import asynccontextmanager
from dataclasses import asdict, dataclass, field
from datetime import datetime, timezone
from io import BytesIO
from pathlib import Path
from typing import TypeVar

import serial
import xlsxwriter
from fastapi import FastAPI, HTTPException, Request
from fastapi.responses import FileResponse, JSONResponse, RedirectResponse, Response
from fastapi.staticfiles import StaticFiles

from app.calibration import CalibrationSample, fit_load_cell_calibration


SetupCommandResult = TypeVar("SetupCommandResult")


PROJECT_DIR = Path(__file__).resolve().parents[1]
STATIC_DIR = Path(__file__).resolve().parent / "static"
DEFAULT_METHOD_DIR = PROJECT_DIR / "data" / "test-methods"
DEFAULT_SAMPLE_SET_DIR = PROJECT_DIR / "data" / "test-sets"
DEFAULT_SERIAL_PORT = "COM3" if platform.system(
).lower().startswith("win") else "/dev/ttyACM0"

# Motion values sent to the Arduino are in motor steps, not millimeters.
MOTION_STEPS_PER_REV = 200.0
MOTION_GEARBOX_RATIO = 19.203
MOTION_SCREW_PITCH_MM_PER_REV = 4.0
MOTION_MICROSTEPPING = 8.0
MOTION_SPEED_MIN = 50.0
MOTION_SPEED_MAX = 4000.0
MOTION_SPEED_DEFAULT = 4000.0
MOTION_ACCELERATION_MIN = 100.0
MOTION_ACCELERATION_MAX = 10000.0
MOTION_ACCELERATION_DEFAULT = 10000.0
MOTION_ACK_TIMEOUT_S = 2.0
MOTION_COMMAND_ATTEMPTS = 3
MOTION_RETRY_DELAY_S = 0.1
TARE_ACK_TIMEOUT_S = 7.0
TARE_COMMAND_ATTEMPTS = 3
TARE_RETRY_DELAY_S = 0.1
DISPLACEMENT_ZERO_ACK_TIMEOUT_S = 2.0
DISPLACEMENT_ZERO_COMMAND_ATTEMPTS = 3
DISPLACEMENT_ZERO_RETRY_DELAY_S = 0.1

TEST_ACK_TIMEOUT_S = 2.0
TEST_COMMAND_ATTEMPTS = 3
TEST_RETRY_DELAY_S = 0.1
TEST_HEARTBEAT_PERIOD_S = 0.5
TEST_HOLD_DURATION_MAX_S = 24.0 * 60.0 * 60.0
TEST_SPEED_MIN = 50.0
TEST_SPEED_MAX = 4000.0
TEST_SPEED_DEFAULT = 2000.0
TEST_TARGET_TYPES = {"FORCE", "DISPLACEMENT"}
TEST_RATE_TYPES = {"FORCE", "DISPLACEMENT"}
SERIAL_LOG_DEFAULT_MAX_LINES = 500
SAMPLE_ID_MAX_LENGTH = 64
SAMPLE_NOTES_MAX_LENGTH = 200
SAMPLE_SET_NAME_MAX_LENGTH = 80
SAMPLE_WORKBOOK_FIELDNAMES = [
    "wall_time_s",
    "controller_time_ms",
    "run_id",
    "frame_mode",
    "step_index",
    "phase",
    "fault_reason",
    "control_mode",
    "setpoint_force_n",
    "setpoint_displacement_mm",
    "force_n",
    "position_mm",
    "step_rate_steps_s",
]
SAMPLE_WORKBOOK_NUMERIC_FIELDS = {
    "wall_time_s",
    "controller_time_ms",
    "run_id",
    "step_index",
    "setpoint_force_n",
    "setpoint_displacement_mm",
    "force_n",
    "position_mm",
    "step_rate_steps_s",
}
SUMMARY_WORKBOOK_FIELDNAMES = [
    "sample_index",
    "sample_id",
    "notes",
    "included",
    "status",
    "method_name",
    "point_count",
    "peak_force_n",
    "peak_force_position_mm",
    "final_force_n",
    "final_position_mm",
]
SUMMARY_WORKBOOK_NUMERIC_FIELDS = {
    "sample_index",
    "point_count",
    "peak_force_n",
    "peak_force_position_mm",
    "final_force_n",
    "final_position_mm",
}
WORKBOOK_FORCE_DISPLACEMENT_MAX_POINTS = 2000
METHOD_NAME_MAX_LENGTH = 80
RETURN_ZERO_MODES = {"LOAD", "DISPLACEMENT"}
RETURN_ZERO_LOAD_DEFAULT_RATE_N_S = 10.0
STEPS_PER_MM = (
    MOTION_STEPS_PER_REV *
    MOTION_GEARBOX_RATIO *
    MOTION_MICROSTEPPING /
    MOTION_SCREW_PITCH_MM_PER_REV
)
RETURN_ZERO_DISPLACEMENT_DEFAULT_RATE_MM_S = TEST_SPEED_DEFAULT / STEPS_PER_MM
RETURN_ZERO_HOLD_DURATION_S = 1.0
RELATIVE_MOVE_AMOUNTS_MM = frozenset({-100.0, -10.0, -1.0, 1.0, 10.0, 100.0})
RELATIVE_MOVE_STATIONARY_STEP_RATE_MAX_STEPS_S = 0.5
RUN_KIND_NONE = "NONE"
RUN_KIND_SPECIMEN = "SPECIMEN"
RUN_KIND_INITIALIZATION = "INITIALIZATION"
RUN_KIND_RETURN_ZERO = "RETURN_ZERO"
RUN_KIND_RELATIVE_MOVE = "RELATIVE_MOVE"
INITIALIZATION_MODE_NONE = "NONE"
INITIALIZATION_MODE_PRELOAD_UNLOAD_ZERO = "PRELOAD_UNLOAD_ZERO_DISPLACEMENT"
INITIALIZATION_MODES = {
    INITIALIZATION_MODE_NONE,
    INITIALIZATION_MODE_PRELOAD_UNLOAD_ZERO,
}
INITIALIZATION_PRELOAD_FORCE_DEFAULT_N = 10.0
INITIALIZATION_UNLOAD_FORCE_DEFAULT_N = 0.0
INITIALIZATION_RATE_DEFAULT_MM_S = 0.02
INITIALIZATION_MAX_TRAVEL_DEFAULT_MM = 2.0
INITIALIZATION_HOLD_DURATION_S = 1.0
CALIBRATION_SAMPLE_DURATION_S = 12.0
CALIBRATION_SAMPLE_POLL_S = 0.02
CALIBRATION_SAMPLE_MIN_COUNT = 20
CALIBRATION_STATIONARY_STEP_RATE_MAX_STEPS_S = 0.5


def sample_included_by_default(status: str) -> bool:
    return status in {"COMPLETE", "STOPPED"}


@dataclass(slots=True)
class AppConfig:
    serial_port: str = os.getenv("TENSILE_SERIAL_PORT", DEFAULT_SERIAL_PORT)
    serial_baudrate: int = int(os.getenv("TENSILE_SERIAL_BAUDRATE", "115200"))
    reconnect_delay_s: float = float(
        os.getenv("TENSILE_SERIAL_RECONNECT_S", "2.0"))
    serial_log_max_lines: int = int(
        os.getenv("TENSILE_SERIAL_LOG_MAX_LINES", str(SERIAL_LOG_DEFAULT_MAX_LINES)))
    method_dir: Path = Path(os.getenv("TENSILE_METHOD_DIR", str(DEFAULT_METHOD_DIR)))
    sample_set_dir: Path = Path(
        os.getenv("TENSILE_SAMPLE_SET_DIR", str(DEFAULT_SAMPLE_SET_DIR)))


@dataclass(slots=True)
class MachineSnapshot:
    # The latest machine reading that the web page polls and displays.
    connected: bool = False
    state: str = "DISCONNECTED"
    frame_mode: str = "DISCONNECTED"
    fault_reason: str = "NONE"
    raw_adc: int = 0
    force_n: float = 0.0
    step_rate_steps_s: float = 0.0
    position_mm: float = 0.0
    button_up: bool = False
    button_down: bool = False
    button_stop: bool = False
    jog_speed_steps_s: float = MOTION_SPEED_DEFAULT
    test_max_step_rate_steps_s: float = TEST_SPEED_DEFAULT
    acceleration_steps_s2: float = MOTION_ACCELERATION_DEFAULT
    telemetry_seq: int = 0
    controller_time_ms: int = 0
    test_run_id: int = 0
    test_phase: str = "NONE"
    test_step_index: int = 0
    test_step_count: int = 0
    test_control_mode: str = "NONE"
    test_setpoint_force_n: float = 0.0
    test_setpoint_displacement_mm: float = 0.0
    test_elapsed_ms: int = 0
    updated_at: float = 0.0
    last_message: str = "Waiting for Arduino."


@dataclass(slots=True)
class MachinePayload:
    frame_mode: str
    test_phase: str
    fault_reason: str
    raw_adc: int
    force_n: float
    step_rate_steps_s: float
    position_mm: float
    button_up: bool
    button_down: bool
    jog_speed_steps_s: float | None
    acceleration_steps_s2: float | None
    button_stop: bool = False
    test_run_id: int = 0
    test_max_step_rate_steps_s: float | None = None
    test_step_index: int = 0
    test_step_count: int = 0
    test_control_mode: str = "NONE"
    test_setpoint_force_n: float = 0.0
    test_setpoint_displacement_mm: float = 0.0
    test_elapsed_ms: int = 0


@dataclass(slots=True)
class TestStep:
    target_type: str
    target_value: float
    rate_type: str
    rate_value_per_s: float
    hold_duration_s: float
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

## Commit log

2025-12-02 sample code to get the stepper spinning!
2025-12-02 run stepper with button press
2025-12-02 continuing v3
    [Assy v3.SLDASM, work.xlsx]
2025-12-05 wip cad
    [5-1 Planetary Gearbox.SLDPRT, Assy v3.SLDASM, NEMA Planetary Gearbox.SLDPRT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]
2025-12-08 cad wip, some analsysis coming together
    [Assy v3.SLDASM, Base Plate.SLDPRT, Cross Head.SLDPRT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]
2025-12-10 cad wip
    [Assy v3.SLDASM, Base Plate.SLDPRT, Columns.SLDPRT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]
2025-12-22 V3, ordered xometry
    [59935K87_Ball Joint Rod End.STEP, 90327A127_Alloy Steel Low-Profile Socket Head Screws.STEP, 90591A220_Zinc-Plated Steel Hex Nut.STEP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]
2025-12-22 adding receipt
    [work.xlsx]
2026-01-17 v1 print
    [v1 print.3mf]
2026-01-18 updated print
    [v1 print.3mf]
2026-01-24 updates to motor mount, fasteners too long :(
    [Assy.SLDASM, Motor bracket.SLDPRT, Motor bracket.STEP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]
2026-01-25 wip cad electronics
    [Assy.SLDASM, Control Box 2.SLDPRT, HX711.SLDPRT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]
2026-01-28 wip electronics
    [Arduino Platform.SLDPRT, Arduino Platform.STEP, RPI Platform.SLDPRT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]
2026-01-29 wip electrical cad
    [Arduino Platform.SLDPRT, Arduino Platform.STEP, RPI Platform.SLDPRT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]
2026-01-30 WIP cad electrical, abandoning PI-arduino stack and moving towards box
    [Arduino Platform.SLDPRT, Control Box 2.SLDPRT, Control Box Assy.SLDASM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]
2026-02-04 wip cad, printed control box 2
    [#2 5-16in 90065A078_18-8 Stainless Steel Phillips Flat Head Screws for Metal.SLDPRT, #5 0p5in 92470A121_Phillips Rounded Head Screws for Sheet Metal.SLDPRT, Co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]
2026-02-06 STEPPERS ARE MOVING!
2026-02-07 control box 3d print
    [Control Box 2.3mf]
2026-05-02 control box cover
    [22mm E-Stop.SLDPRT, Control Box Assy.SLDASM, Control Box Outer.SLDPRT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]
2026-05-06 control box outer updates
    [Control Box Outer.3mf, Control Box Outer.STEP]
2026-05-13 cad updates
    [8020 Cable Cap Clip 5mm.STEP, 8020 Cable Cap Clip 9mm.STEP, 8020 Cable Cap Clip.SLDPRT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]
2026-05-15 lets see how this goes
    simplifications
    link checker
    Update virtual environment activation command in README
    Update README with Arduino board listing command
    Added instructions to list connected Arduino boards using arduino-cli.
    409 fix
    409 fix 2
    503 fix
    massive simplify
    button updates
    bug fix
    stepper bug fixing
    more bug fixes
    debug text boxes
    [HardwareConfig.h, main.cpp, main.py]
2026-05-17 variable speed
    robust ack
    serial output window
    echo errors
    io bugfix
    simplify pass
    simplify setup ena
    cad and load cell pinout
    max speed
    speed
    speed
    speed and microstepping updates
    [#2 5-16in 90065A078_18-8 Stainless Steel Phillips Flat Head Screws for Metal.SLDPRT, Amplifier Mount Block.SLDPRT, Amplifier Mount Block.STEP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]
2026-05-18 calibration update
2026-05-18 tare
    button formatting
    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
    [HardwareConfig.h, main.cpp, main.py]
2026-06-02 first round of test program
    bugfix
    state refactor
    plotting
    commanded force plot
    simple PID
    control and plotting
    simplify
    logging fix
    test complete phase
    plotting controls
    Make Python Test Completion And Terminal States Explicit
    plot resizing
    standards
    control box and gripper
    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
    [Control Box 2.SLDPRT, Control Box Assy.SLDASM, Control Box Base.SLDPRT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]
2026-06-16 Add calibration functionality and UI components
    - Introduced CalibrationSample data class to represent calibration data.
    - Implemented calibration sampling logic in SerialMonitor with methods to capture ADC values.
    - Added endpoints for calibration sampling and fitting in the FastAPI application.
    - Created a new HTML structure for the calibration interface, including status, capture controls, and results display.
    - Enhanced JavaScript to manage calibration state, capture points, and fit calibration data.
    - Added unit tests for calibration fitting and sampling to ensure functionality and error handling.
    - Updated styles for calibration components to improve layout and usability.
    Enhance cali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
    [Gripper Assy.SLDASM, Gripper Insert 3mm.STEP, Gripper Insert.SLDPRT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]
2026-06-17 feat: implement test method management with save/load functionality
    - Added TestMethod and TestMethodStore classes for managing test methods.
    - Implemented API endpoints for listing, retrieving, and saving test methods.
    - Enhanced the UI to allow users to save and load test methods with corresponding dialogs.
    - Updated the test sample records to include method details (ID, name, hash).
    - Introduced method validation and parsing functions to ensure correct method structure.
    - Added unit tests for method storage, retrieval, and validation.
    [main.py]
2026-06-17 fix: update default max step rate and related UI values for improved motion control
    [HardwareConfig.h, main.py]
2026-06-17 feat: update sample ID handling and display in UI, enhance test metadata parsing
2026-06-17 feat: add sample notes editing functionality and update related UI components
2026-06-17 feat: implement sample set management with save and open functionality
2026-06-17 feat: enhance sample set workbook with summary and method worksheets, add support for empty sets
2026-06-18 feat: update button styles and add new step action buttons with icons in the sample set panel
2026-06-18 feat: update README and code to enhance sample workbook details and improve chart handling
2026-06-21 CAD cleanup
    [17HS19-2004D-E1K.SLDPRT, 5-8 Coupler.SLDPRT, 698-2RS Deep Groove Ball Bearing.SLDPRT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]
2026-06-26 Update Tensile Gripper 7x7mm.3mf file with new design modifications
    [Lap Shear Coupon 7x7mm.3mf, Lap Shear Coupon 7x7mm.SLDPRT, Lap Shear Coupon 7x7mm.STEP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]
2026-06-26 feat: update sample inclusion logic and improve test assertions for stopped samples
